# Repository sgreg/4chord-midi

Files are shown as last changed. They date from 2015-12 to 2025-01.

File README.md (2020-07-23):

# 4chord MIDI - The Four Chord USB MIDI Keyboard

What does it take to create a hit pop song?

Australia's former comedy group [The Axis of Awesome](https://en.wikipedia.org/wiki/The_Axis_of_Awesome) had the answer: [Four chords](https://www.youtube.com/watch?v=5pidokakU4I). Though not just any four chords, but the [I-V-vi-IV chord progression](https://en.wikipedia.org/wiki/I%E2%80%93V%E2%80%93vi%E2%80%93IV_progression) to be precise. This project implements a USB MIDI device for the purpose of playing this exact four-chord progression.

4chord MIDI is a regular USB MIDI controller, just like any other MIDI keyboard, except it has just four buttons, one for each chord in the I-V-vi-IV chord progression, playable in any key. But since simply playing chords is a bit limiting, it also features different playback modes such as triad arpeggios and chords mixed with arpeggios. Additionally, the tempo of each note progression is selectable from 30bpm to 240bpm. It's even shaped like a piano, to give the real feel of playing an actual musical instrument.

For additional information, check out [the 4chord MIDI project website](https://4chord.craplab.fi) and [its hackaday.io project page](https://hackaday.io/project/26078-4chord-midi).

4chord MIDI is fully open source and certified as such by the [Open Source Hardware Association (OSHWA)](https://www.oshwa.org/). The hardware is licensed under the [CERN Open Hardware License v.1.2](http://www.ohwr.org/projects/cernohl/wiki) and the software is released under the [GNU General Public License version 2](http://www.gnu.org/licenses/old-licenses/gpl-2.0.en.html).

<p align="center">
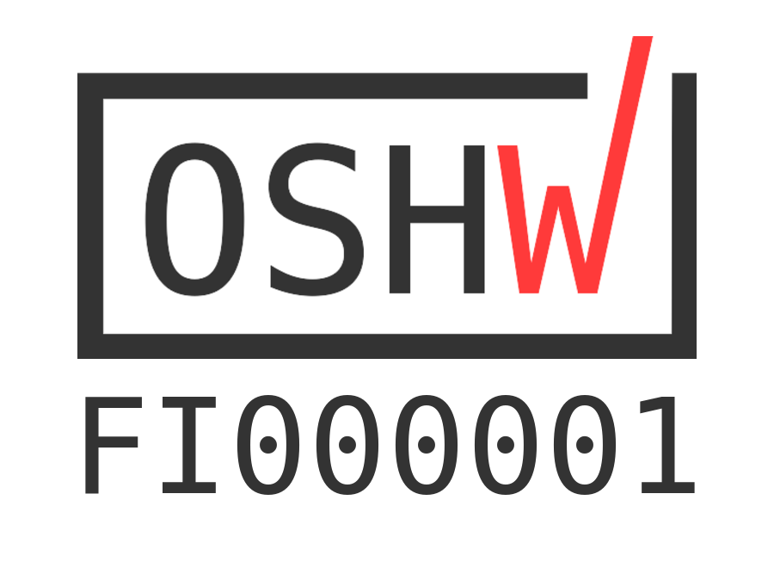
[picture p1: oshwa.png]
[OSHW] FI000001 Finland Number One!

</p>

## Table of Contents
  * [Quick Start](#quick-start)
  * [Project Structure](#project-structure)
  * [Build it](#build-it)
  * [Flash it](#flash-it)
  * [Use it](#use-it)
  * [User Interface](#user-interface)
  * [Troubleshooting](#troubleshooting)

## Quick Start

If you're not interested in the details, here's the quickest way to build and flash a 4chord MIDI device. Note that the Makefile is set up to expect USBasp as programmer. If you're using a different programmer, check the [flashing section](#flash-it) for more details.

### Dependencies
Make sure you have the dependencies to build the bootloader and firmware installed on your system.

For Ubuntu, Debian, and the likes, this should be:
```
$ sudo apt install gcc-avr avr-libc avr-binutils avrdude make
```
For Fedora etc. it should be:
```
$ sudo dnf install avr-gcc avr-libc avr-binutils avrdude make
```
For Arch it should be ~~FUCKING OBVIOUS AND YOU'RE NOT WORTHY TO USE THIS GLORIOUS DISTRO IF YOU HAVE TO ASK A LAME QUESTION LIKE THIS~~ the same package names as for Fedora:
```
$ sudo pacman -S avr-gcc avr-libc avr-binutils avrdude make
```

Unfortunately, I don't have the answer for any other distribution, MacOS, or Windows, but essentially, it's just the regular AVR toolchain components (and `make`), so checking a general setup guide for the AVR toolchain on that system should get you there. Presumably it follows the same package names as mentioned so far.

### Cloning, Building, Flashing

Clone the repository and change into it:
```
$ git clone https://github.com/sgreg/4chord-midi.git
$ cd 4chord-midi/
```

Build the bootloader and firmware:
```
$ make
```

Make sure the ATmega's fuses are set up properly:
```
$ make fuses
```

Flash it to the device:
```
$ make program
```

That's it, your 4chord MIDI device should be ready to go, and once plugged in, recognized as as such. Check the [usage section](#use-it) for a quick overview of how to connect it to *FluidSynth* to get your first chords played.

If you *are* interested in more details, well here they come.

## Project Structure

* [`bootloader/`](bootloader/) the bootloader for comfortable firmware update flashing
* [`doc/`](doc/) some relevant documentation such as USB specifications
* [`firmware/`](firmware/) the main 4chord MIDI firmware code
* [`graphics/`](graphics/) raw [XBM](https://en.wikipedia.org/wiki/X_BitMap) files used within the GUI and intro animation
* [`hardware/`](hardware/) schematic and PCB design files
* [`sys/`](sys/) Linux system scripts (udev rules and setup scripts)
* [`tools/`](tools/) additional tools to convert graphics and dump fuse settings
* [`Makefile`](Makefile) main entry point to built it all
* [`common.mk`](common.mk) shared data related to building
* everything else: this README and git stuff

## Build it

From firmware point of view, there are three main parts to build here:
1. the raw XBM graphics converted to easily dump to the Nokia LCD (shipped pre-built)
1. the bootloader for future firmware updates via USB (optional but recommended)
1. the actual firmware

### Graphics
As the graphics parts come pre-built ([`intro.c`](firmware/intro.c)/[`intro.h`](firmware/intro.h) for the intro animation, [`gfx.c`](firmware/gfx.c)/[`gfx.h`](firmware/gfx.h) for all GUI related graphic elements), there's nothing to do, unless you want to change the [`graphics/`](graphics/) content by either adding new XBM files, or modifying the existing ones. In that case, once the graphics are modified, run:
```
$ make graphics
```
from the project's root path, which will delete all previously generated files and re-create them.

### Bootloader

You can build and flash the bootloader on its own without the main 4chord MIDI firmware. If this is your first time with the code, you might want to skip this option and go straight to the [Bootloader with Firmware](#bootloader-with-firmware) section for now.

But let's say you want to play around with just the bootloader and flash the application firmware through USB later, or make modifications to the bootloader itself. In that case, the bootloader can be built from the project's root directory via
```
$ make bootloader
```

or from within the `bootloader/device/` directory via `make` on its own.

This will create the bootloader's ELF and HEX file in the `bootloader/device/` directory, ready to be flashed to the device. Instructions on flashing [follow below](#flash-it).

**Note that this will build only the bootloader but not the firmware, so the device won't act as USB MIDI controller afterwards!**

Also note that once [flashed](#flash-it), the bootloader needs to be manually activated by pressing the *Select* button when powering the device up, otherwise it will fall through to the application code - which in this case won't exist. As a result, the device is stuck in a boot loop until the *Select* key is pressed. In other words, if the device seems dead after flashing the bootloader, just press the *Select* button to start up the actual bootloader.

### Firmware

As with the bootloader mentioned above, the firmware can be built and flashed on its own without adding the bootloader to it. This makes sense if you make any changes to the firmware code without touching the bootloader, but keep in mind that [flashing](#flash-it) the firmware on its own will leave out the bootloader, so future firmware updates via USB won't be possible (but you can always just re-flash the device with both components, so there's no harm done).

To build the firmware on its own from the project root directory, simply call

```
$ make firmware
```

To build it straight from within the `firmware/` directory, simply run `make` in there.

This will again create the ELF and HEX file inside the `firmware/` directory, and in addition, a BIN file. The HEX file is used for [flashing](#flash-it), while the BIN file is used in the firmware upgrade via USB using the bootloader.

### Bootloader with Firmware

To get the full package of bootloader and firmware, simply call
```
$ make
```
from within the project's root directory.

This will build both components separately, and the resulting ELF, HEX, and in case of the firmware, BIN file will be afterwards located in `bootloader/device/` and `firmware/` respectively.

You should now have either one of them built and ready to be flashed to the device.

## Flash it

If you're building your own device, you will require an AVR programmer to flash the initial bootloader and/or firmware to it. If you got a ready-made device, it will come with an initial bootloader and firmware already flashed on it, in which case you can either still use an AVR programmer to update it, or use the bootloader's built-in update functionality.

### Flashing with an AVR Programmer

The build system is set up to expect USBasp as programmer, so if you're using a different programmer, flashing is of course going to fail. To set up the build system for your programmer, check the [`common.mk`](common.mk) file for the following line:

```
AVRDUDE_PROGRAMMER_FLAGS = -c usbasp
```
and adjust it to your needs. If the programmer requires an additional port parameter, add the `-P <port>` accordingly.

Note that the device uses a 6-pin ISP connector, although some programmers - including a regular USBasp programmer - comes with a 10-pin connector. The 10-pin version has in the end just 4 additional, unused pins, which seems unnecessary, so the choice was to go for the 6-pin version here. The connectors are otherwise compatible, it just needs either an adapter or manual wiring.

To make sure the programmer is set up properly, connect it to the 4chord MIDI device and run
```
$ make check-programmer
```
from within the project's root directory. If both the programmer and device was detected, you should `SUCCESS` displayed in the end. Note that if you didn't connect the 4chord MIDI device, you might still see `FAILURE` even though the programmer is set up correctly. `avrdude`'s error message should hopefully give some hints which part went wrong then.

If everything is happily set up, connect the programmer to the device and get ready to flash.

Depending on the parts you [built earlier](#build-it), you can either flash the bootloader and firmware on its own, or nicely combined for the full experience.

For the latter, run the following command from the project's root directory:
```
$ make program
```
To flash only the bootloader, which won't include the firmware itself and therefore won't turn the device into an actual MIDI controller, run the command from within the bootloader directory:
```
$ cd bootloader/device/
$ make program
```
To flash only the firmware without the bootloader, flash it from the firmware's directory accordingly:
```
$ cd firmware/
$ make program
```

In case you included the firmware in your flashing, you're ready to [use it](#use-it). If you only flashed the bootloader and want to add the firmware through it, keep reading.

### Flashing via Bootloader

Whether the device runs *only* the bootloader, or the whole package, as long as there's a bootloader, you can use it to flash the actual 4chord MIDI firmware on it.

Flashing the firmware via bootloader involves two parts:
1. the activated bootloader on the device
2. the host-side flashing tool

To activate the bootloader, press the *Select* button while you power up the device, i.e. keep the *Select* button pressed when you plug in the USB cable to either your computer or the device itself. Instead of the 4chord MIDI startup animation and its user interface, you'll be greeted by the bootflash screen, telling you to feed it firmware.

The [host-side flashing tool](bootloader/host/) is a Python script using [PyUSB](https://github.com/pyusb/pyusb) to communicate with the bootloader - so make sure you have both Python 3 and the PyUSB module installed, whether through `pip` or your Linux distro's package manager.

With the device set up to receive new firmware, change into the host-side flashing tool's directory and run the script, giving the path of the new firmware's BIN file. If you built the firmware from its regular location, it will look like this:
```
$ cd bootloader/host/
$ ./bootflash.py ../../firmware/4chordmidi.bin
```

As you run the script, you will see some information and progress status displayed on the command line, and the device will show a progress bar on its screen. Once everything is done, you're ready to boot into the new firmware.

You can either just unplug the cable and plug it back in (making sure not to press the *Select* button this time), or press the *I* and *IV* playback button (i.e. the left-most and right-most white buttons).

## Use it

This section exclusive covers using the device under Linux, but since 4chord MIDI implements standard USB and MIDI specifications, other operating systems should treat it just like any other MIDI device. The general instructions of using MIDI devices on other operating systems should therefore apply also to 4chord MIDI.

### Plug it in

Connect 4chord MIDI to your computer and check if it got recognized. `dmesg` or the system log should show something like this:
```
[3038097.883853] usb 1-1.1.1: new low-speed USB device number 112 using ehci-pci
[3038099.140623] usb 1-1.1.1: New USB device found, idVendor=1209, idProduct=deaf
[3038099.140626] usb 1-1.1.1: New USB device strings: Mfr=1, Product=2, SerialNumber=0
[3038099.140627] usb 1-1.1.1: Product: 4chord MIDI
[3038099.140628] usb 1-1.1.1: Manufacturer: CrapLab
```

And thanks to [pid.codes](http://pid.codes/), `lsusb` should show something like this:
```
Bus 001 Device 112: ID 1209:deaf Generic CrapLab 4chord MIDI
```
Of course, the bus and device number will most certainly differ, but as long as the VID/PID pair (`1209:deaf`) is the same, it's all good.

### Simple playback with FluidSynth

As 4chord MIDI is just the controller in the MIDI chain, you will need a synthesizer to turn the playback into actual music. A cross-platform choice for this is for example the [FluidSynth software synthesizer](https://en.wikipedia.org/wiki/FluidSynth) in combination with its related sound font files.

FluidSynth can use different audio driver, including ALSA, PulseAudio, and [jack](https://en.wikipedia.org/wiki/JACK_Audio_Connection_Kit). To make life easy, let's use ALSA for this example.

#### Dependencies
Here's how to install ALSA utilities, FluidSynth with the sound fonts, and the resulting path of the sound font file we'll need afterwards.

Ubuntu / Debian / etc:
```
$ sudo apt install fluidsyinth fluid-soundfont-gm alsa-utils
/usr/share/sounds/sf2/FluidR3_GM.sf2
```
Note that the soundfont might also be named `fluidsynth-soundfont-gm` in older versions

Fedora etc:
```
$ sudo dnf install fluidsynth fluid-soundfont-gm alsa-utils
/usr/share/soundfonts/FluidR3_GM.sf2
```
Arch:
```
$ sudo pacman -S fluidsynth soundfont-fluid alsa-utils
/usr/share/soundfonts/FluidR3_GM.sf2
```

Again, for other distributions and operating systems, check the internet.

#### Running FluidSynth

Open up a terminal and start FluidSynth:

```
$ fluidsynth -a alsa -m alsa_seq /usr/share/soundfonts/FluidR3_GM.sf2
```

Make sure to use the correct sound font path according to your distro / operating system.

Once FluidSynth is started, and a 4chord MIDI device is connected to your computer, we need to connect the two using `aconnect` from the ALSA utils. Open up another terminal and check the input and output port IDs of the two parties involved.

```
$ aconnect -i
client 20: '4chord MIDI' [type=kernel]
    0 '4chord MIDI MIDI 1'

$ aconnect -o
client 129: 'FLUID Synth (32590)' [type=user]
    0 'Synth input port (32590:0)'
```

Your output probably shows more devices in each command, but those are the ones to look for. It tells us that 4chord MIDI is input port `20:0` and FluidSynth as MIDI output is port `129:0`. All that's left to do is connect the two:

```
$ aconnect 20:0 129:0
```

That's it. If you press any of the white playback buttons, you should hear a piano sound of the chords. Congratulations!

#### Changing instruments

If you want a change from the default Yamaha Grand Piano, go back to the terminal that runs FluidSynth and check the list of available instruments within its own command line. Since there's only one sound font file, its ID is simply `1`.
```
> inst 1
000-000 Yamaha Grand Piano
000-001 Bright Yamaha Grand
000-002 Electric Piano
...
000-025 Steel String Guitar
...
>
```

Changing the playback instrument for example to the Steel String Guitar (instrument id 25) for the default MIDI channel 0 is done via the `prog <chan> <instrument>` command:
```
> prog 0 25
```

You should now hear a guitar sound from the 4chord MIDI device.

### Automatic FluidSynth Setup

If you want to start FluidSynth automatically when you connect a 4chord MIDI device to you computer, you can do so on Linux with a udev rule. Check the [`sys/udev/`](sys/udev/) directory for further information on that.

## User Interface

If you got this far and everything worked as described, congratulations once again - and to both of us I guess, seeing that what I wrote actually worked out. If it didn't, well, there's a [troubleshooting section](#troubleshooting) still to come.

Now that the device is ready to be fully used, it's time give a quick introduction to its user interface.

### Display

The display consists of 4 components:
1. the menu bar on top, showing key, mode, tempo, and metre, underlining the one currently active
1. the playback setup information in form of key (C, C#, ..., Bb), tempo (30...240), metre (4/4, 3/4. 6/8), and playback mode (chord, arpeggios - shown in a simple form of musical notation)
1. the available chords for the currently selected key, highlighting the one that is currently played
1. a metronome if the playback mode is not just the simple chord playback

The menu buttons will control the content on the display.

### Menu Buttons
The three black buttons - `<`, `Select`, and `>` - serve as menu buttons and are used to control the key, mode, tempo, and metre:
* `Select` toggles between which part to control, i.e. key, mode, tempo, or metre
* `<` and `>` choose each part's value in an down/up and previous/next manner respectively

For example, if the *key* is the active component, and the active key is "C", `<` will change it to "Bb", and `>` will change it to "C#". Pressing `Select` twice will set the active component to `tempo`, and `<` will not decrease it, while `>` will increase it.

Both `<` and `>` have a long-press feature, meaning if keeping the button pressed, multiple press events are recognized, eventually speeding up.

For the time being, a long press on the `Select` button will save the current setup (key, mode, tempo, metre) as the device's default settings, so next time the device is powered on, it will recover those as its initial state.

### Playback buttons

The four playback buttons - `I`, `V`, `vi`, `IV` - are used to play each one of the four chords. That's basically it.

And yes, this section could most certainly use some visual aid.

## Troubleshooting

Obviously, everything I write and explain *works for me*&trade;, so it's difficult to anticipate difficulties others might have. Therefore the list of known problems is pretty limited at this point, but feel free to open an issue or contact me you come across some problems yourself.

#### Nothing happens when plugging in the device, and the display stays black
The flash might be either empty, or only the bootloader was flashed. Press the *Select* button and see if a bootflash screen comes up on the display. If yes, the application side wasn't flashed. If not, try re-flashing everything. See the [flashing section](#flash-it) either way.

#### Flashing firmware via bootloader fails with `usb.core.USBError: [Errno 13] Access denied (insufficient permissions)`
The device permissions are not set up for your user. You can either use `sudo`, or check the [bootloader/ directory](bootloader/) README about setting up a udev rule.

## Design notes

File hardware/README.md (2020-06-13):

# 4chord MIDI schematic and PCB layout files

**Note:** All content was designed using KiCad 4. This should be updated to KiCad 5 eventually. Schematics are additionally provided in PDF and PCB layouts in Gerber format.

## Subdirectory content:

- Atmega328-TQFP32:
    - SMD version
    - 32pin TQFP ATmega328
    - Nokia 5110 clip-in LCD

## Notes on the Nokia 5110 LCD
There are several options to source the LCD with its clip-in frame, the most common one being the breakout board version of it. In some cases you might find the standalone LCD without breakout board.

KiCad didn't have footprints for it, so I created one that is available in my [kicad-libs repo](https://github.com/sgreg/kicad-libs), with more information available [on its dedicated hackady.io project page](https://hackaday.io/project/25666-yet-another-nokia-5110-lcd-breakout-board).

## Notes on PCB artwork
As with the LCD connector footprints, the logos used on the PCB can be found in my [kicad-libs repo](https://github.com/sgreg/kicad-libs).

## License
The 4chord MIDI documentation is released as Open Hardware under the CERN OHL v.1.2.

You may redistribute and modify this documentation under the terms of the [CERN OHL v.1.2](http://ohwr.org/cernohl).
This documentation is distributed WITHOUT ANY EXPRESS OR IMPLIED WARRANTY, INCLUDING OF MERCHANTABILITY, SATISFACTORY QUALITY AND FITNESS FOR A PARTICULAR PURPOSE. Please see the CERN OHL v.1.2 for applicable conditions

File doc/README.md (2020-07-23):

## Documentation

A selection of documentation and specifications relevent to 4chord MIDI.

The original locations are linked within the firmware code, e.g. [`usb.h`](../firmware/usb.h). However, those locations have changed in the past, and old links resulted in 404 or redirects. To make everyone's life easier in case it happens again at some point in the future, I just added their copies here.

### Content

* [`audio10.pdf`](audio10.pdf) _USB Device Class Specification for Audio Devices_  
originally found at https://usb.org/sites/default/files/audio10.pdf
* [`midi10.pdf`](midi10.pdf) _USB Device Class Specification for MIDI Devices_  
originally found at https://usb.org/sites/default/files/midi10.pdf
* [`Summary_of_MIDI_Messages.pdf`](Summary_of_MIDI_Messages.pdf) _Summary of MIDI Messages_ table as found at https://www.midi.org/specifications/item/table-1-summary-of-midi-message (basically printed that page to PDF)

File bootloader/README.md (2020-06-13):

# 4chord MIDI Bootloader

The bootloader allows to update the 4chord MIDI firmware through USB. It uses a rather simple, home-brew protocol to set up the firmware transfer, transfer and flash the firmware itself, as well as writing EEPROM data. It consists of a host-side and a device-side part, with the host side initiating the transfer, and the device-side flashing chunks of the new firmware file as it receives it.

## Protocol

The protocol used to communicate between the host-side Python script and the device-side firmware uses USB control transfers and looks like this:

| Command | Type | Hex |  Description |
| --- | ---- |  --- | ---- |
| HELLO | Recv | `0x01` | Initiates communication and retrieves the bootloader version string of size 'buffer'|
| FWUPDATE_INIT | Send | `0x10` | Initiates firmware transfer, giving the number of expected 128 byte chunks|
| FWUPDATE_MEMPAGE  | Send | `0x11` | Transfer a single firmware chunk |
| FWUPDATE_VERIFY | Recv | `0x12` | Read back the last transferred firmware chunk for verification |
| FWUPDATE_FINALIZE | Send | `0x13` | Finalize firmware transfer |
| EEPROM_READ | Recv | `0x20` | Read EEPROM value from a given address |
| EEPROMT_WRITE | Send | `0x30` | Write EEPROM value to a given address |
| BYE | Send | `0xf0` | Terminate the communication |
| RESET | Send | `0xfa` | Reset the device |

With the Python script being the initiating side, the Recv/Send type refers to its point of view.

### Device Side

On the device side, the bootloader firmware is located in the ATmega's dedicated bootloader memory section, and the communication is implemented via V-USB.

#### State machine

There's a simple state machine on the device side making sure that everything has its order.

| State | Description
|  --- | --- |
| IDLE | No communication initiated, requires `HELLO` command |
| HELLO | Communication initiated, ready to either start firmware update via `FWUPDATE_INIT` command or EEPROM operations |
| FWUPDATE | Firmware update ongoing, only `FWUPDATE_*` related commands are handled |
| RESET | Device reset initiated

#### Debug build

In case you want to modify the device-side bootloader firmware and have to debug something, it can be built with a `DEBUG` flag that adds extra debug output via UART. However, due to size limitations, enabling UART debug will disable graphical output on the LCD. So it's either LCD or UART, and without the `DEBUG` flag, no UART functions are available. Also, flashing with debug output enabled is really slow.

If you switch between `DEBUG` and normal built, it's best to `make clean` between the builds.

### Host Side

To run the host-side bootflash script, Python 3, PyUSB, and a udev rule to allow access to the device is needed. Using `sudo` or being root will also do for the latter, but nothing wrong with a udev rule to make life easier.

#### udev rule

There are two options to set up the permissions: set the device ownership to the current user, or set the device's read and write permission for everyone. The more flexible one is the latter, and would like this:

```
SUBSYSTEM=="usb", ATTRS{idVendor}=="1209", ATTRS{idProduct}=="deaf", MODE="0666"
```

You can either manually copy this to a udev file in `/etc/udev/rules.d/`, or use the installation script in the repository's [`sys/udev/` directory](../sys/udev/) to do it automatically.

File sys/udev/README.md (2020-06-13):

## 4chord MIDI udev rule example

Just some proof of concept to have a script run whenever a 4chord MIDI device is plugged in and unplugged. In this case, it will automatically setup the MIDI connection to fluidsynth when the device is plugged in. If fluidsynth isn't running, it will start it. When the device is unplugged, everything is nicely cleaned up again.

In addition, another rule will set up the permission for the device so any user can flash it via the bootloader.

There are a few files to get this done:

* `4chordMIDI-bootflash.rules` the udev rule file to set up the permission
* `4chordMIDI-fluidsynth.sh` the actual script taking care of the whole fluidsynth and MIDI connection setup handling
* `4chordMIDI-fluidsynth.rules` the udev rule template that will actually handle the script execution
* `install.sh` installation script to set it all up

The udev rule will executed by root while the whole fluidsynth and MIDI setup needs to be run by a regular user, so the script needs to be executed using `su - <user>` to make it work properly. The user name needs to be hard coded to the udev rule file, so to avoid doing this manually, I added the `install.sh` script. It also lets you choose the udev rule file prefix.

### Known Issues

The udev rule doesn't seem to work too well with (at least) Arch Linux. While the `4chordMIDI-fluidsynth.sh` script gets executed, and fluidsynth is trying to start, it doesn't succeed due to some underlything ALSA issues. Possibly just some configuration issue but haven't gotten around to finding a solution yet.
 - **Workaround 1**: have the udev rule still in place, but start fluidsynth manually *before* plugging in the 4chord MIDI device
 - **Workaround 2**: ditch the whole udev part and run `4chordMIDI-fluidsynth.sh` manually *after* plugging in the device

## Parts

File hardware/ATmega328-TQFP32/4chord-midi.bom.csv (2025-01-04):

Reference | Value | Datasheet | Footprint | Qty | DNP
C1,C2 | 10u |  | Capacitors_Tantalum_SMD:CP_Tantalum_Case-A_EIA-3216-18_Hand | 2
C3,C4,C5,C8,C9,C10,C11,C12,C13,C14,C15,C16 | 100n |  | Capacitors_SMD:C_0805_HandSoldering | 12
C6,C7 | 27p |  | Capacitors_SMD:C_0805_HandSoldering | 2
D1,D2,D3,D4 | LED |  | LEDs:LED_0805 | 4
IC1 | ATMEGA328P-A |  | Housings_QFP:TQFP-32_7x7mm_Pitch0.8mm | 1
P1 | USB_B |  | Connect:USB_Mini-B | 1
P2 | Programmer |  | Connect:IDC_Header_Straight_6pins | 1
P3 | UART |  | Pin_Headers:Pin_Header_Straight_1x04_Pitch2.54mm | 1
P4 | UART Power |  | Pin_Headers:Pin_Header_Straight_1x04_Pitch2.54mm | 1
Q1 | 2N7002 |  | TO_SOT_Packages_SMD:SOT-23 | 1
R1,R2 | 68R |  | Resistors_SMD:R_0805_HandSoldering | 2
R3 | 1k5 |  | Resistors_SMD:R_0805_HandSoldering | 1
R4,R17 | 1M |  | Resistors_SMD:R_0805_HandSoldering | 2
R5,R6,R7,R8,R9,R10,R11,R18 | 10k |  | Resistors_SMD:R_0805_HandSoldering | 8
R12,R13,R14,R15,R16 | 100 |  | Resistors_SMD:R_0805_HandSoldering | 5
SW1 | < |  | Buttons_Switches_SMD:SW_SPST_EVPBF | 1
SW2 | Select |  | Buttons_Switches_SMD:SW_SPST_EVPBF | 1
SW3 | > |  | Buttons_Switches_SMD:SW_SPST_EVPBF | 1
SW4 | I |  | Buttons_Switches_SMD:SW_SPST_EVPBF | 1
SW5 | V |  | Buttons_Switches_SMD:SW_SPST_EVPBF | 1
SW6 | vi |  | Buttons_Switches_SMD:SW_SPST_EVPBF | 1
SW7 | IV |  | Buttons_Switches_SMD:SW_SPST_EVPBF | 1
U1 | LD1117S33CTR |  | TO_SOT_Packages_SMD:SOT-223 | 1
U2 | Nokia_5110_LCD |  | Nokia_5110-3310_LCD:Nokia_5110-3310_LCD | 1
X1 | 12MHz |  | Crystals:Crystal_SMD_HC49-SD | 1

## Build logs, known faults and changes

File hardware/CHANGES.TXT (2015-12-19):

********************************************************************************
*                                 CHANGES.TXT                                  *
********************************************************************************
Modifications made by Licensee.

********************************************************************************

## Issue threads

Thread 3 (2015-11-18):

Add USB MIDI handling

sgreg, 2015-11-18:
Implement basic USB MIDI support via V-USB.
* Setup as MIDI device
* Single note MIDI command send on chord button key press

sgreg, 2015-11-22:
Completed with pull request #6 merge

Closed 2015-11-22.

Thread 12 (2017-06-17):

Create Revision B schematic

sgreg, 2017-06-17:
Update schematic for Revision B

* Change crystal
* Change LCD + back light

sgreg, 2017-07-02:
Changed crystal, LCD and back light. Adjusted pins for better PCB routing

Closed 2017-07-02.

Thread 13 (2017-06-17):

Create Revision B PCB

sgreg, 2017-06-17:
Create a more interesting PCB and add issue #12 changes.

sgreg, 2017-07-02:
New PCB designed and routed, left some debug options around for now (zero ohm links to power supplies, UART interface)

Closed 2017-07-02.

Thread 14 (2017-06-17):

Update firmware to Revision B hardware changes

sgreg, 2017-06-17:
Adjust clock speed to lower speed crystal and any other changes (e.g. pin assignments)

sgreg, 2017-07-02:
* V-USB pins need adjustments, too
* new LCD needs different bias system configuration (`0x14` vs `0x12`)
* LCD backlight *handling* not part of this issue, only its pin assignment

sgreg, 2017-07-23:
Set firmware version to 1.1 after all the adjustments and create release "Firmware version 1.1, Hardware revision B" as clear base between initial Rev.A version and any changes coming for next firmware versions.

sgreg, 2017-07-23:
All adjustments done, at least in theory, there's no way to fully verify it without the hardware. Waiting for PCBs to arrive before closing the issue.

Closed 2017-08-01.

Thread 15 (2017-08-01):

Create Revision B.1 PCB

sgreg, 2017-08-01:
Revision B PCB needs some minor modifications:

- LCD back light transistor uses wrong component that messes up pin assignment
- move from bipolar transistor to MOSFET along the way
- zero Ohm links won't be necessary anymore
- button foot print is not an ideal fit for buttons in use, either one needs some changing
- UART connector's VCC pin needs a voltage selector for 0V, 3.3V, 5V to keep flexibility with serial connectors (used as debug interface for developers)
- additional rubber foot required on the top side, otherwise board topples when pressing "<" button
- some silk screen adjustments (button text needs to be lower, polarized capacitors lack polarity markings)

sgreg, 2017-08-19:
Everything done, Revision B hardware is now ready \o/

szwesleyzhao, 2017-08-19:
Cool, do you need turnkey pcb assembly service in china ? We could one stop stop service from prototype to mass production. Here is email; szhwpcba@gmail.com

sgreg, 2017-08-19:
Thanks, but I got everything I need covered for now.

Closed 2017-08-19.

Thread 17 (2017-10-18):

Add bootloader

sgreg, 2017-10-18:
Implement USB bootloader to firmware for updating itself:
* execute if "Select" menu key is pressed during power up
* show on LCD that bootloader is active
* wait for host side transfer initiation and firmware meta data (version, size, ...)
* receive firmware one memory page at a time and write it to flash
* read back freshly written flash page and send it back to host
* continue until host is happy and firmware is fully updated

Implement host side tool:
* simple Python CLI script
* search for right VID:PID and connect to it
* read firmware image and send one page at a time
* read back memory page from device and verify content - either re-send or move on

Update Makefile:
* build both bootloader and application firmware
* convert application firmware .hex file to binary blob data

sgreg, 2017-10-25:
Done and merged in #26

Closed 2017-10-25.

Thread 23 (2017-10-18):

Improve LCD handling

sgreg, 2017-10-18:
Currently the LCD content is buffered in the microcontroller RAM which takes up a large chunk of it. See if it's feasible to remove the buffering and update the LCD on the fly (as in [xbm2nokia](https://github.com/sgreg/xbm2nokia)).

Add funky startup animation along the way.

sgreg, 2017-10-20:
Also time to retire tools/create_graphics.* at that point and integrate [xbm2nokia](https://github.com/sgreg/xbm2nokia).

sgreg, 2017-10-28:
Done in #27 - no more useless buffering in RAM.

Didn't do the tool change though, still using the old tools/create_graphics.sh based script instead of xbm2nokia. Some other day..

Closed 2017-10-28.

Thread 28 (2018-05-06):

Integrate xbm2nokia

sgreg, 2018-05-06:
There's currently a mix of using the old graphics creation script and fixed graphics created by [xbm2nokia](https://github.com/sgreg/xbm2nokia). The old script should be fully replaced with xbm2nokia and integrated into the build system accordingly.

Closed 2018-12-23.

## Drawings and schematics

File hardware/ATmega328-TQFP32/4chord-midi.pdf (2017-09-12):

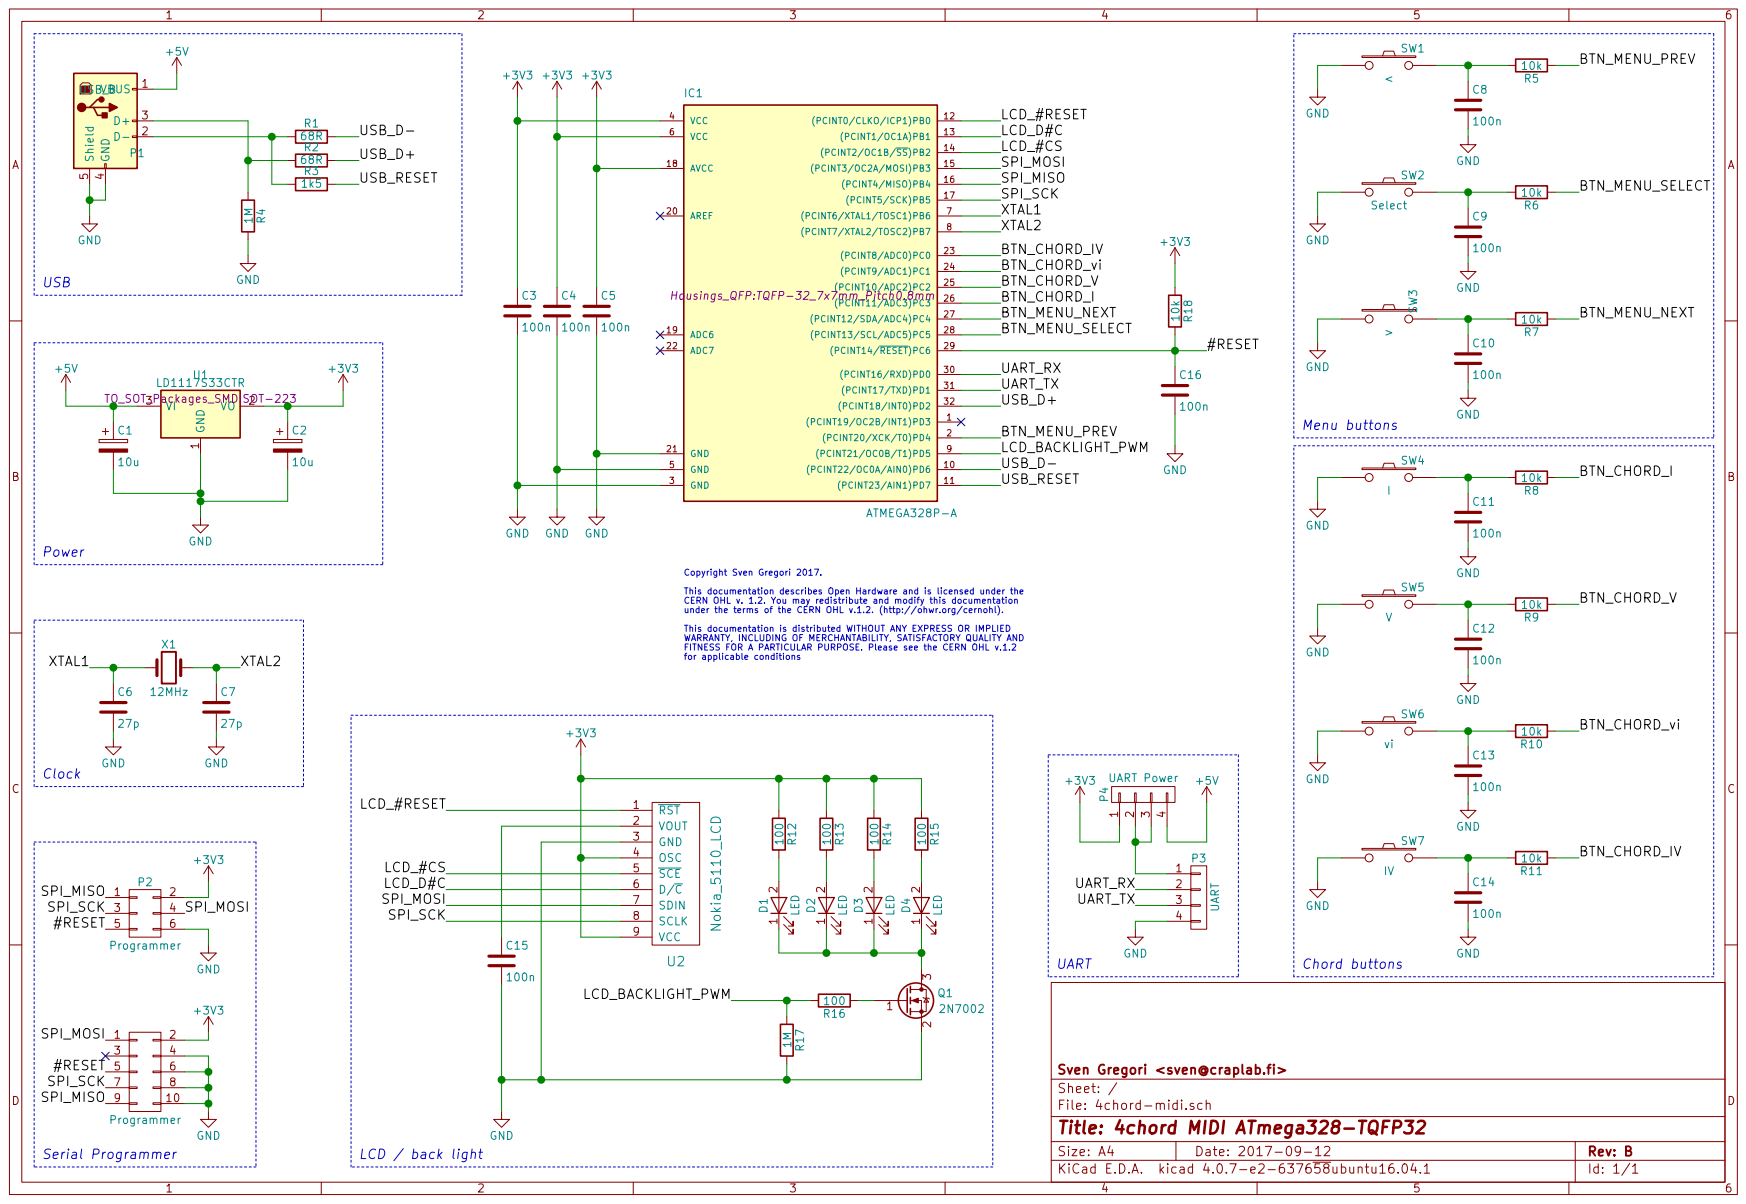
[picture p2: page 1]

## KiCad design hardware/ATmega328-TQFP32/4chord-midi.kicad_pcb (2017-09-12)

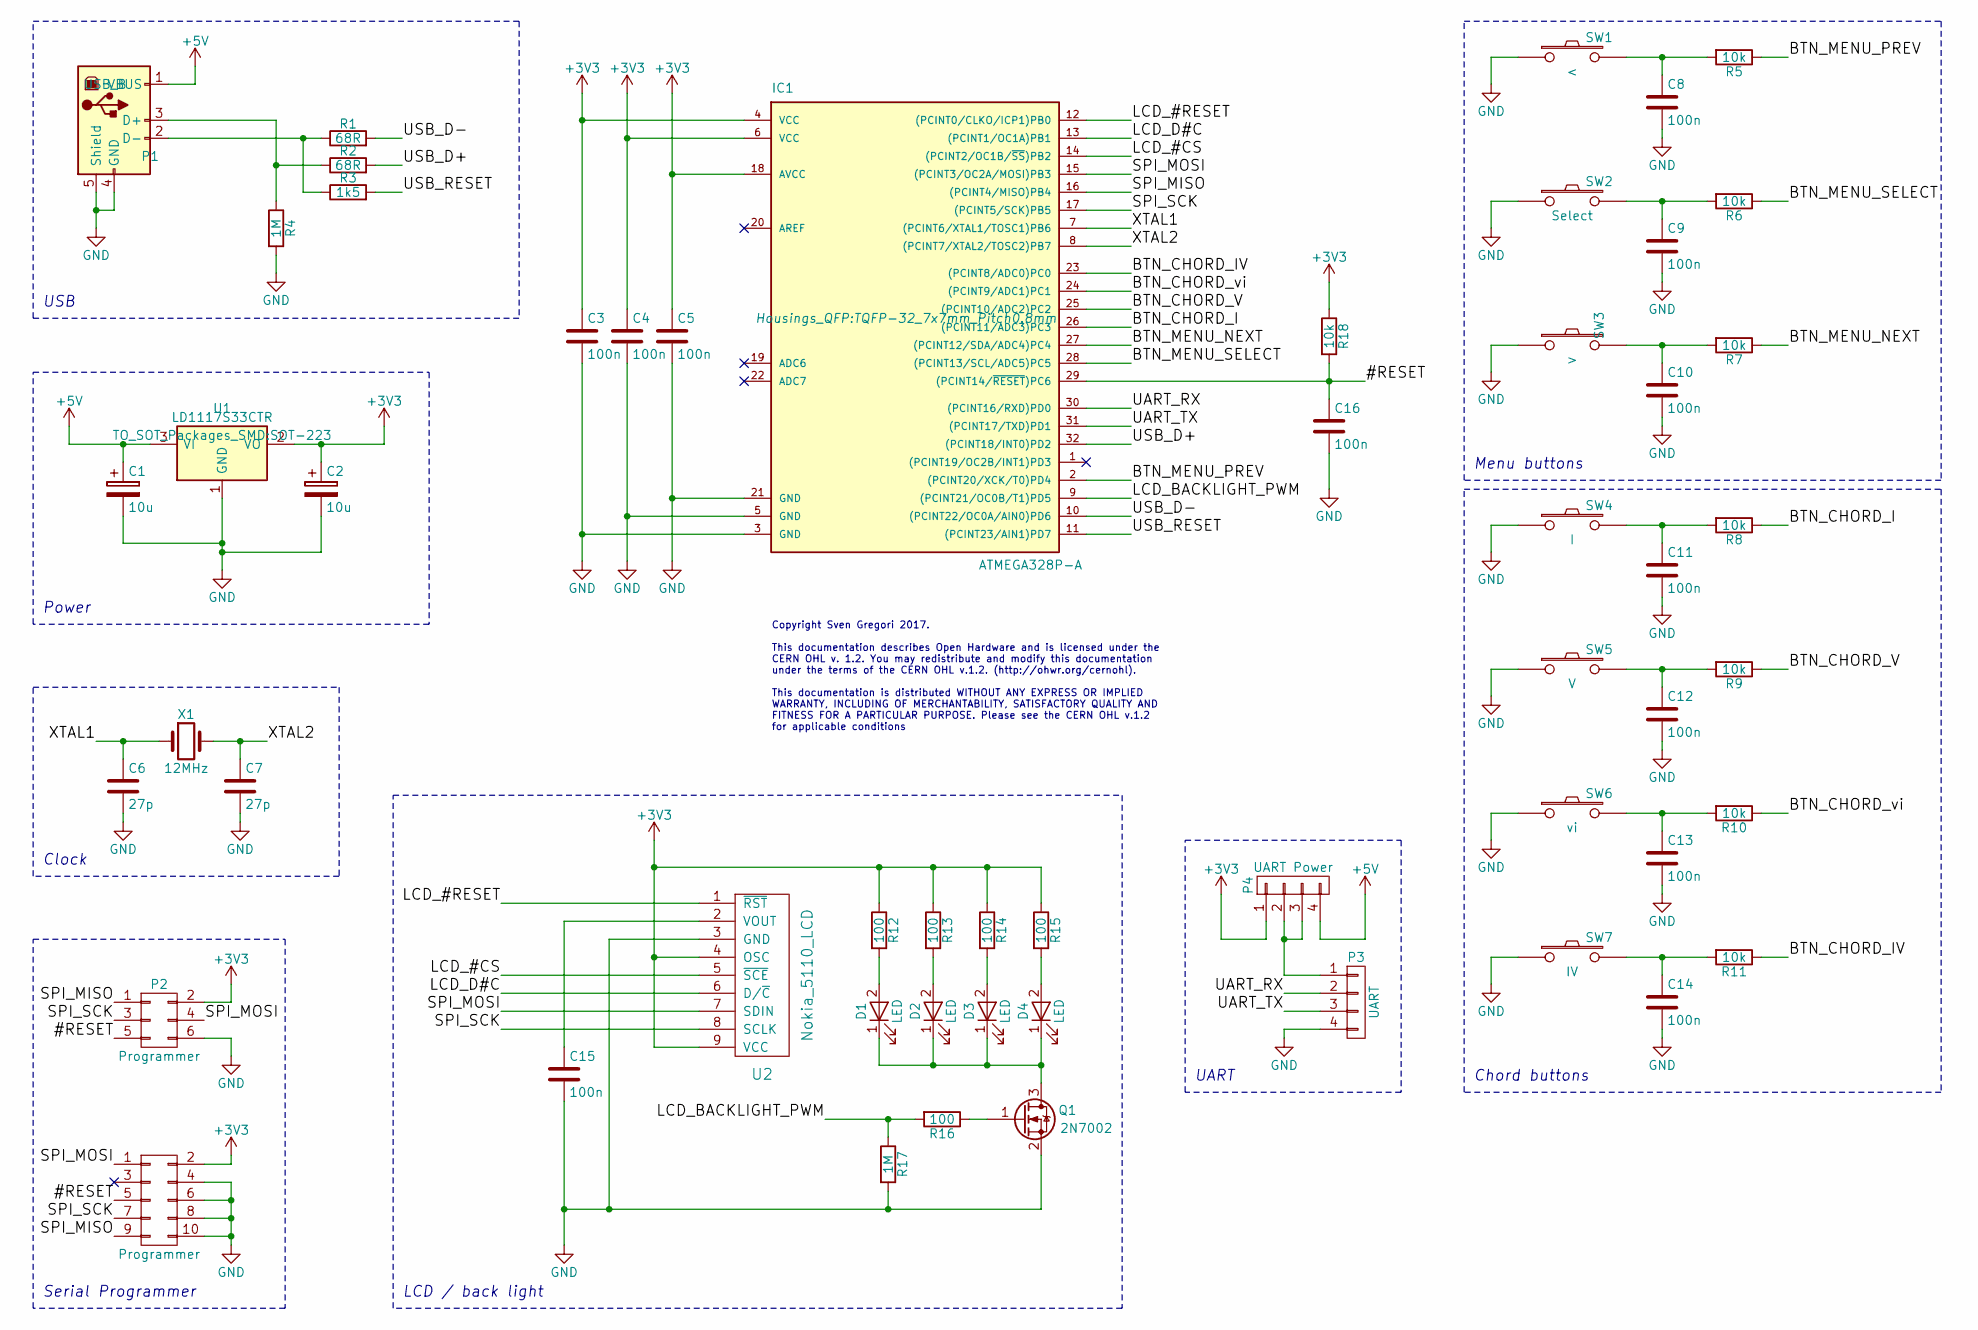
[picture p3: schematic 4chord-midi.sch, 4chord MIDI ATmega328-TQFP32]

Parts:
C1, C2: 10u; CP_Tantalum_Case-A_EIA-3216-18_Hand
C3, C4, C5, C8, C9, C10, C11, C12, C13, C14, C15, C16: 100n; C_0805_HandSoldering
C6, C7: 27p; C_0805_HandSoldering
D1, D2, D3, D4: LED; LED_0805
IC1: ATMEGA328P-A; TQFP-32_7x7mm_Pitch0.8mm
P1: USB_B; USB_Mini-B
P2: Programmer; IDC_Header_Straight_6pins
P3: UART; Pin_Header_Straight_1x04_Pitch2.54mm
P4: UART Power; Pin_Header_Straight_1x04_Pitch2.54mm
Q1: 2N7002; SOT-23
R1, R2: 68R; R_0805_HandSoldering
R3: 1k5; R_0805_HandSoldering
R4, R17: 1M; R_0805_HandSoldering
R5, R6, R7, R8, R9, R10, R11, R18: 10k; R_0805_HandSoldering
R12, R13, R14, R15, R16: 100; R_0805_HandSoldering
SW1: <; SW_SPST_EVPBF
SW2: Select; SW_SPST_EVPBF
SW3: >; SW_SPST_EVPBF
SW4: I; SW_SPST_EVPBF
SW5: V; SW_SPST_EVPBF
SW6: vi; SW_SPST_EVPBF
SW7: IV; SW_SPST_EVPBF
U1: LD1117S33CTR; SOT-223
U2: Nokia_5110_LCD; Nokia_5110-3310_LCD
X1: 12MHz; Crystal_SMD_HC49-SD

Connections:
+5V: C1.1, P1.1 (VBUS), P4.4, U1.3 (VI)
/BTN_CHORD_I: IC1.26 ((PCINT11/ADC3)PC3), R8.1
/BTN_CHORD_IV: IC1.23 ((PCINT8/ADC0)PC0), R11.1
/BTN_CHORD_V: IC1.25 ((PCINT10/ADC2)PC2), R9.1
/BTN_CHORD_vi: IC1.24 ((PCINT9/ADC1)PC1), R10.1
/BTN_MENU_NEXT: IC1.27 ((PCINT12/SDA/ADC4)PC4), R7.1
/BTN_MENU_PREV: IC1.2 ((PCINT20/XCK/T0)PD4), R5.1
/BTN_MENU_SELECT: IC1.28 ((PCINT13/SCL/ADC5)PC5), R6.1
/LCD_#CS: IC1.14 ((PCINT2/OC1B/~SS~)PB2), U2.5 (~SCE)
/LCD_#RESET: IC1.12 ((PCINT0/CLKO/ICP1)PB0), U2.1 (~RST)
/LCD_BACKLIGHT_PWM: IC1.9 ((PCINT21/OC0B/T1)PD5), R16.2, R17.1
/LCD_D#C: IC1.13 ((PCINT1/OC1A)PB1), U2.6 (D/~C)
/UART_RX: IC1.30 ((PCINT16/RXD)PD0), P3.2
/UART_TX: IC1.31 ((PCINT17/TXD)PD1), P3.3
/USB_D+: IC1.32 ((PCINT18/INT0)PD2), R2.2
/USB_D-: IC1.10 ((PCINT22/OC0A/AIN0)PD6), R1.2
/USB_RESET: IC1.11 ((PCINT23/AIN1)PD7), R3.2
/XTAL1: C6.1, IC1.7 ((PCINT6/XTAL1/TOSC1)PB6), X1.1
/XTAL2: C7.1, IC1.8 ((PCINT7/XTAL2/TOSC2)PB7), X1.2
unnamed: C8.1, R5.2, SW1.2
unnamed: C9.1, R6.2, SW2.2
unnamed: C10.1, R7.2, SW3.2
unnamed: C11.1, R8.2, SW4.2
unnamed: C12.1, R9.2, SW5.2
unnamed: C13.1, R10.2, SW6.2
unnamed: C14.1, R11.2, SW7.2
unnamed: C15.1, U2.2 (VOUT)
unnamed: D1.1 (K), D2.1 (K), D3.1 (K), D4.1 (K), Q1.3 (D)
unnamed: D1.2 (A), R12.2
unnamed: D2.2 (A), R13.2
unnamed: D3.2 (A), R14.2
unnamed: D4.2 (A), R15.2
unnamed: P1.2 (D-), R1.1, R3.1
unnamed: P1.3 (D+), R2.1, R4.1
unnamed: P3.1, P4.2, P4.3
unnamed: Q1.1 (G), R16.1

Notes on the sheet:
Copyright Sven Gregori 2017. This documentation describes Open Hardware and is licensed under the CERN OHL v. 1.2. You may redistribute and modify this documentation under the terms of the CERN OHL v.1.2. (http://ohwr.org/cernohl). This documentation is distributed WITHOUT ANY EXPRESS OR IMPLIED WA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
Clock
Serial Programmer
LCD / back light
Power
USB
UART
Menu buttons
Chord buttons

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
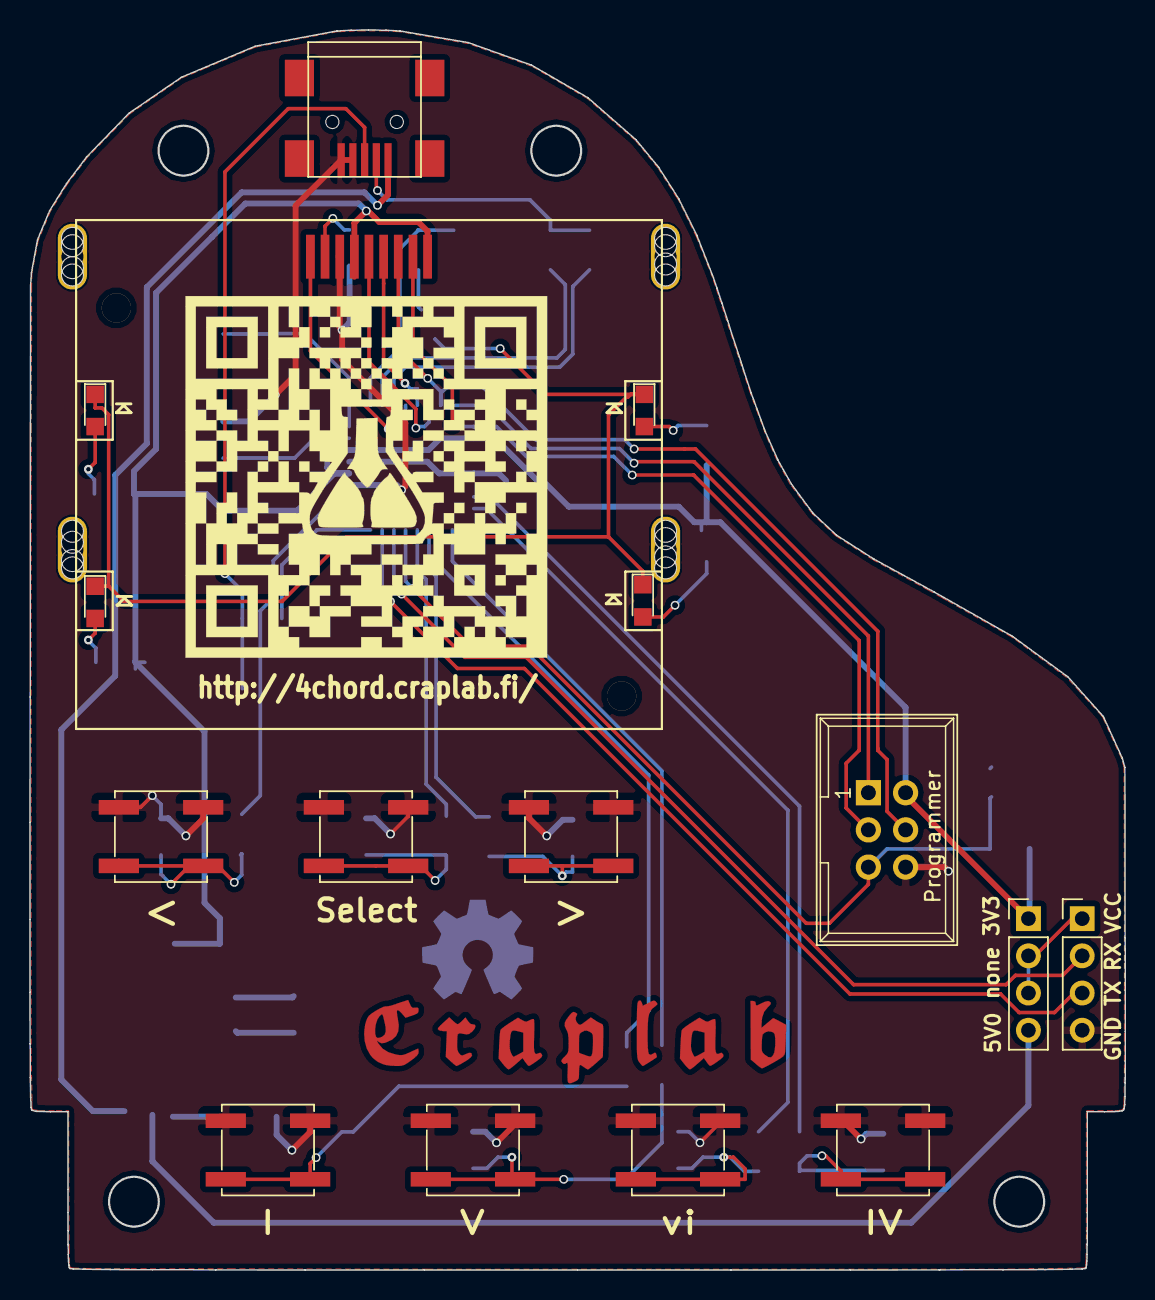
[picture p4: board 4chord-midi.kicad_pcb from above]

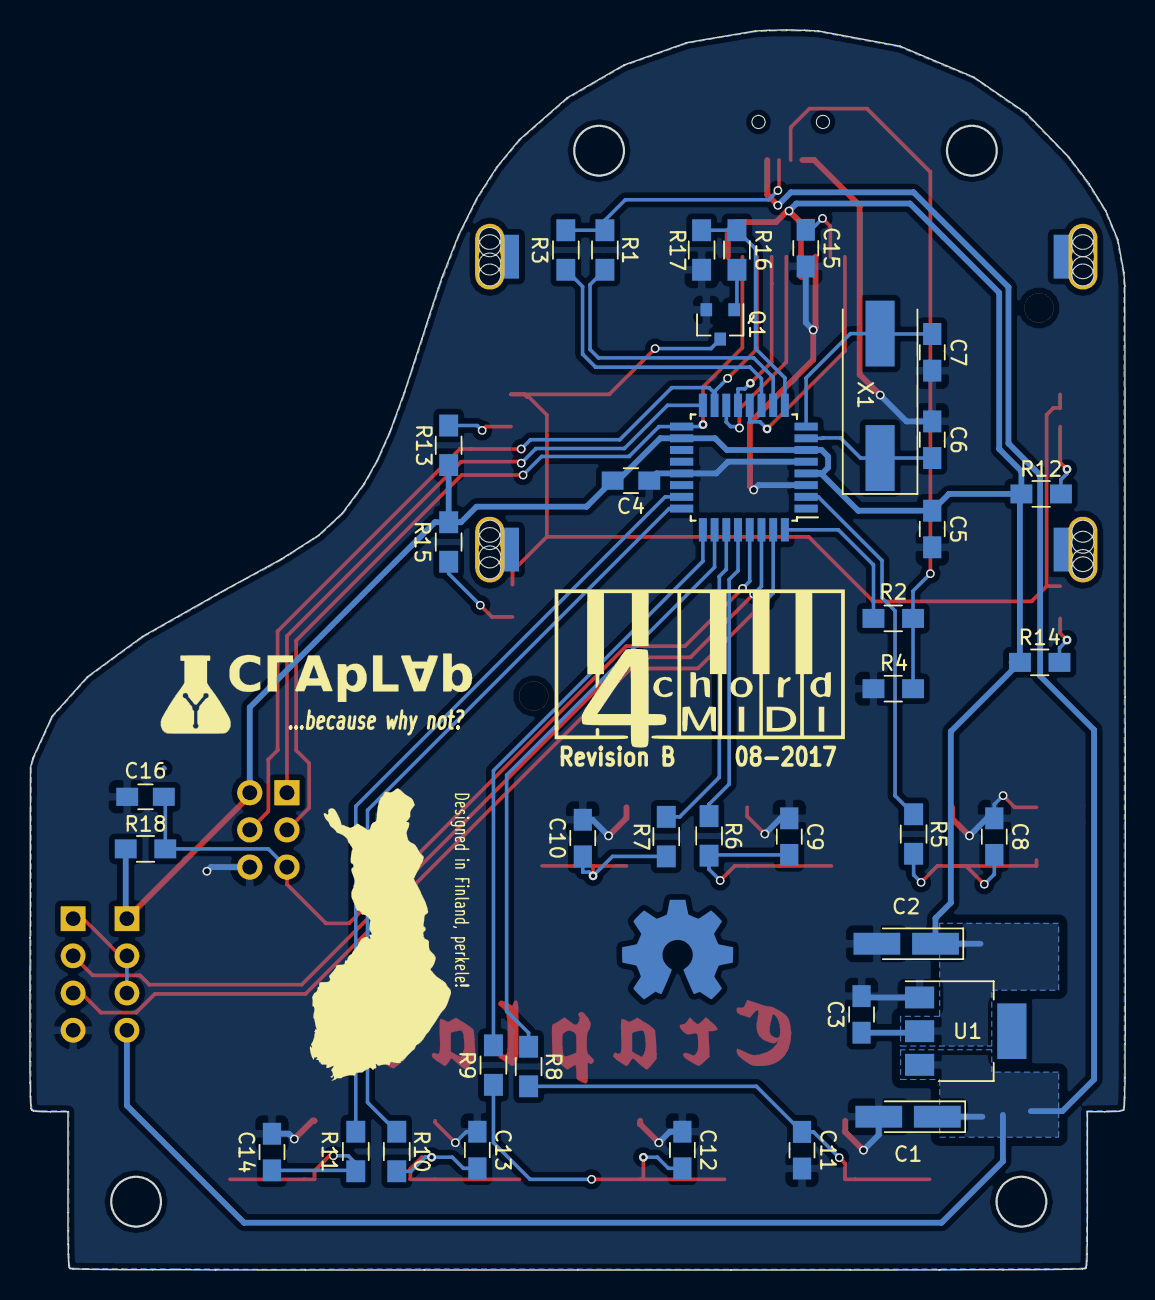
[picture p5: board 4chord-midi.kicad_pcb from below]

Board: 2 copper layers, 74.8 x 84.7 mm, 62 parts (43 on the bottom side), 42 nets.

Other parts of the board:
G1: LOGO; craplab-fraktur-Mask
G2: LOGO; craplab-fraktur-Cu
G3: LOGO; oshw-mask
G4: LOGO; oshw-cooper
G11: qr; projpage-QR-code-inv
G12: 4chordmidi; 4chord-midi
G22: craplab
G31: finland

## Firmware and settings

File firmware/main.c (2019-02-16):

/*
 * 4chord MIDI - main
 *
 * Copyright (C) 2019 Sven Gregori <sven@craplab.fi>
 *
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
 *
 * ATmega328 pin layout (TQFP32)
 *
 *   1  PD3     (unused)
 *   2  PD4     I   Button menu prev
 *   3  GND     -
 *   4  VCC     -
 *   5  GND     -
 *   6  VCC     -
 *   7  PB6     -   XTAL1
 *   8  PB7     -   XTAL2
 *
 *   9  PD5     O   LCD back light
 *  10  PD6     I   USB D-
 *  11  PD7     O   USB Reset
 *  12  PB0     O   LCD /Reset
 *  13  PB1     O   LCD D/C
 *  14  PB2     O   LCD /CS
 *  15  PB3     O   LCD MOSI / SerProg MOSI
 *  16  PB4     I   SerProg MISO
 *
 *  17  PB5     O   LCD SCK / SerProg SCK
 *  18  AVCC    -
 *  19  ADC6    (unused)
 *  20  AREF    -
 *  21  GND     -
 *  22  ADC7    (unused)
 *  23  PC0     I   Button Chord IV
 *  24  PC1     I   Button Chord vi
 *
 *  25  PC2     I   Button Chord V
 *  26  PC3     I   Button Chord I
 *  27  PC4     I   Button Menu Select
 *  28  PC5     I   Button Menu Next
 *  29  PC6     -   /Reset
 *  30  PD0     I   UART RXD
 *  31  PD1     O   UART TXD
 *  32  PD2     I   USB D+
 *
 */
#include <stdint.h>
#include <avr/interrupt.h>
#include <avr/io.h>
#include <util/delay.h>
#include "buttons.h"
#include "cli.h"
#include "eeprom.h"
#include "lcd.h"
#include "menu.h"
#include "xbmlib.h"
#include "intro.h"
#include "gui.h"
#include "playback.h"
#include "spi.h"
#include "timer.h"
#include "uart.h"
#include "usbdrv/usbdrv.h"

/** number of steps to increase the PWM timer value during the intro */
#define INTRO_PWM_STEP_INCREASE 4

/** number of PWM timer increase steps per single intro frame */
#define INTRO_PWM_STEPS_PER_FRAME 5


int
main(void) {
    /* half the frame count of the intro animation, start USB at that point */
    const uint8_t frame_count_usb_threshold = intro_frames_count >> 1;
    /* PWM timer value for fading LCD back light during intro animation */
    uint8_t pwm_value;
    /* intro animation frame count */
    uint8_t frame;
    /* a happy little counter */
    uint8_t i;

    /* set PB0, PB1, PB2, PB3, PB4 as output, rest input */
    DDRB  = (1 << DDB0) | (1 << DDB1) | (1 << DDB2) | (1 << DDB3) | (1 << DDB5);
    /* set PB2 high, all other outputs low, enable pullups for all inputs */
    PORTB = ~((1 << PB0) | (1 << PB1) | (1 << PB3) | (1 << PB5));
    /* set port C all inputs */
    DDRC = 0x00;
    /* enable pullups for all inputs */
    PORTC = 0xff;
    /* set PD1 and PD5 as output, rest input. */
    DDRD  = (1 << DDD1) | (1 << DDD5);
    /* set outputs high, enable pullups for all inputs except V-USB ones */
    PORTD = ~((1 << PD2) | (1 << PD5) | (1 << PD6) | (1 << PD7)) & 0xff;

    uart_init(UART_BRATE_38400_12MHZ);
    uart_clear_screen();

    spi_init();
    lcd_rst_low();

    /* this should give enough delay for the LCD to reset */
    eeprom_init();
    cli_print();

    lcd_rst_high();
    lcd_init();

    /* set up LCD backlight timer and show the first intro animation frame */
    timer0_init_pwm();

    sei();

    /*
     * disconnect USB for a while to get (re-)enumeration ongoing
     * see also http://vusb.wikidot.com/driver-api
     */
    usbDeviceDisconnect();

    /*
     * show the intro animation and fade the back light up
     *  - linear PWM duty cycle increase every 10ms
     *  - show next frame after every 50ms
     * after half the animation frames, connect and initialize USB
     * every animation frame after that, start polling to keep the connection
     */
    for (frame = 0, pwm_value = 0; frame < intro_frames_count; frame++) {
        for (i = 0; i < INTRO_PWM_STEPS_PER_FRAME; i++) {
            timer0_set_pwm(pwm_value);
            pwm_value += INTRO_PWM_STEP_INCREASE;
            _delay_ms(10);
        }

        lcd_write_frame(&intro_frames[frame]);

        if (frame == frame_count_usb_threshold) {
            usbDeviceConnect();
            usbInit();
        } else if (frame > frame_count_usb_threshold) {
            usbPoll();
        }
    }

    /* wait some more to show the logo and slowly get the back light all up */
    while (pwm_value) {
        timer0_set_pwm(pwm_value++);
        usbPoll();
        _delay_ms(50);
    }

    /* map buttons to inputs */
    button_map_port(BUTTON_MENU_PREV,   &PIND, 4);
    button_map_port(BUTTON_MENU_SELECT, &PINC, 5);
    button_map_port(BUTTON_MENU_NEXT,   &PINC, 4);
    button_map_port(BUTTON_CHORD_I,     &PINC, 3);
    button_map_port(BUTTON_CHORD_V,     &PINC, 2);
    button_map_port(BUTTON_CHORD_vi,    &PINC, 1);
    button_map_port(BUTTON_CHORD_IV,    &PINC, 0);

    /* clear the display and show the menu */
    lcd_clear();
    menu_init();

    /* let the magic begin */
    while (1) {
        usbPoll();
        button_input_loop();
        playback_poll();
        menu_poll();
        cli_poll();
    }
}

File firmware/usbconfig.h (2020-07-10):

/* Name: usbconfig.h
 * Project: V-USB, virtual USB port for Atmel's(r) AVR(r) microcontrollers
 * Author: Christian Starkjohann
 * Creation Date: 2005-04-01
 * Tabsize: 4
 * Copyright: (c) 2005 by OBJECTIVE DEVELOPMENT Software GmbH
 * License: GNU GPL v2 (see License.txt), GNU GPL v3 or proprietary (CommercialLicense.txt)
 */

/*
 * Based on vusb-20121206/usbdrv/usbconfig-prototype.h
 * Adjusted for the 4chord MIDI project
 */

#ifndef __usbconfig_h_included__
#define __usbconfig_h_included__

/* ---------------------------- Hardware Config ---------------------------- */

#define USB_CFG_IOPORTNAME      D
/* This is the port where the USB bus is connected. When you configure it to
 * "B", the registers PORTB, PINB and DDRB will be used.
 */
#define USB_CFG_DMINUS_BIT      6
/* This is the bit number in USB_CFG_IOPORT where the USB D- line is connected.
 * This may be any bit in the port.
 */
#define USB_CFG_DPLUS_BIT       2
/* This is the bit number in USB_CFG_IOPORT where the USB D+ line is connected.
 * This may be any bit in the port. Please note that D+ must also be connected
 * to interrupt pin INT0! [You can also use other interrupts, see section
 * "Optional MCU Description" below, or you can connect D- to the interrupt, as
 * it is required if you use the USB_COUNT_SOF feature. If you use D- for the
 * interrupt, the USB interrupt will also be triggered at Start-Of-Frame
 * markers every millisecond.]
 */
#define USB_CFG_CLOCK_KHZ       (F_CPU/1000)
/* Clock rate of the AVR in kHz. Legal values are 12000, 12800, 15000, 16000,
 * 16500, 18000 and 20000. The 12.8 MHz and 16.5 MHz versions of the code
 * require no crystal, they tolerate +/- 1% deviation from the nominal
 * frequency. All other rates require a precision of 2000 ppm and thus a
 * crystal!
 * Since F_CPU should be defined to your actual clock rate anyway, you should
 * not need to modify this setting.
 */
#define USB_CFG_CHECK_CRC       0
/* Define this to 1 if you want that the driver checks integrity of incoming
 * data packets (CRC checks). CRC checks cost quite a bit of code size and are
 * currently only available for 18 MHz crystal clock. You must choose
 * USB_CFG_CLOCK_KHZ = 18000 if you enable this option.
 */

/* ----------------------- Optional Hardware Config ------------------------ */

#define USB_CFG_PULLUP_IOPORTNAME   D
/* If you connect the 1.5k pullup resistor from D- to a port pin instead of
 * V+, you can connect and disconnect the device from firmware by calling
 * the macros usbDeviceConnect() and usbDeviceDisconnect() (see usbdrv.h).
 * This constant defines the port on which the pullup resistor is connected.
 */
#define USB_CFG_PULLUP_BIT          7
/* This constant defines the bit number in USB_CFG_PULLUP_IOPORT (defined
 * above) where the 1.5k pullup resistor is connected. See description
 * above for details.
 */

/* --------------------------- Functional Range ---------------------------- */
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

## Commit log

2015-11-15 Initial commit, basic button handling, LCD handling and GUI
2015-11-19 issue-#3: integration of V-USB (and adding sources), setting up MIDI descriptors
    [main.c, usbconfig.h]
2015-11-21 issue-#3: adjust fuses and firmware to 16MHz external clock
    [main.c]
2015-11-21 Add fuse dump tool to display AVR ATmega328p fuse byte settings
2015-11-22 issue-#3: re-arrange startup code to make USB work
    [main.c]
2015-11-22 issue-#3: Added single-note MIDI playback on chord button press
2015-12-03 Added KiCad project for ATmega328-TQFP32
2015-12-03 issue-#1: Added schematic revision A for ATmega328-TQFP32
    [4chord-midi.sch]
2015-12-03 Added KiCad backup and cache files
2015-12-03 issue-#1: fixed broken connection R4-GND
    [4chord-midi.sch]
2015-12-03 issue-#1: Added test points and zero-Ohm links
    [4chord-midi.sch]
2015-12-04 issue-#1: Added ground test points / pins
    [4chord-midi.sch]
2015-12-06 issue-#2: Added component footprints
    [4chord-midi.sch]
2015-12-06 issue-#2: Removed some grounding pins and changed footprints of remaining ones
    [4chord-midi.sch]
2015-12-14 issue-#2: Added KiCad PCB layout
    [4chord-midi.kicad_pcb]
2015-12-14 issue-#2: Added Gerber files (KiCad naming scheme)
    [4chord-midi-B.Cu.gbr, 4chord-midi-B.Mask.gbr, 4chord-midi-B.SilkS.gbr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]
2015-12-14 Added KiCad PCB backup file
2015-12-14 Added comments on PCB artwork
2015-12-14 issue-#3: Added OSH Park compliant Gerber files as ZIP archive and script to create the ZIP archive from KiCad 4 naming scheme
2015-12-18 issue-#4: Moved menu handling from gui.c to new menu.c
    [main.c]
2015-12-19 Added CERN OHL v.1.2 licensing documentation
    [4chord-midi.kicad_pcb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]
2015-12-19 issue-#5: Added progressive playback handling for arpeggio and mixed chord/arpeggio modes
    [main.c]
2015-12-20 issue-#5: Changed timer value calculation to avoid floating point operation
2015-12-20 issue-#5: Added UART command line interface handling for button emulation
    [cli.c, main.c]
2015-12-20 issue-#5: Removed unused case code
    [cli.c]
2017-06-17 issue-#12: Initial version for Revision B hardware
    Changed crystal value from 16MHz to 12MHz to match speed spec for
    ATmega running at 3.3V. Changed LCD from Olimex Nokia 3310 with hard
    to find connector to Nokia 5110 breakout board style so it can be
    clipped directly into the PCB. Added LED based back light as well.
    Adjusted some pin assignments for ongoing PCB design
    Added BOM along the way.
    [4chord-midi-B.Cu.gbr, 4chord-midi-B.Mask.gbr, 4chord-midi-B.SilkS.gbr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]
2017-07-02 issue-#12: Completing Revision B schematic
    Further pin adjustments to get better PCB routing done. Changed
    programmer header from 10pin to 6pin for same reason.
    [4chord-midi.sch]
2017-07-02 issue-#13: Initial Revision B PCB design
    Piano shaped PCB with debug interfaces: zero ohm links to all major
    power supplies, GND and UART voltage supply; GND test point; allows
    external (USB) UART connection (NOTE: do not equip R20 if USB UART
    controller is used)
    [4chord-midi.kicad_pcb]
2017-07-23 issue-#14: Adjust firmware to Revision B hardware changes
    Adjusted pin assignments according to Revision B hardware, changed clock
    frequency define from 16MHz to 12MHz (and re-arranged and neated up the
    Makefile along the way), enabled LCD backlight and changed LCD's bias
    system value for Nokia 5110 display.
    All okay in theory, waiting for PCB to build hardware and fully verify.
    [cli.c, main.c, usbconfig.h]
2017-08-01 issue-#14: Adjust UART baud rate values for 12MHz
    Removed 8MHz and 16MHz based baud rate register values and added 12MHz
    values for baud rates 9600, 19200, 38400 and 57600. Kept 38400 as
    default value for now.
    Note, tried 115200, but error was too large.
    [main.c, uart.h]
2017-08-09 issue-#13: Revised Revision B hardware
    Reworked schematic to separate to logical blocks, added reset circuit,
    fixed Q1 pin assignment and changed it from BJT to MOSFET component.
    Also added power supply choices for UART (5V, 3.3V and none) and a
    fourth rubber foot for better balance.
    Obviously same changes in the PCB design, also moved button silk screen
    bit more down for better readability. Fixed one sharp corner in the
    board border. Improved routing somewhat.
    [4chord-midi-B.Cu.gbl, 4chord-midi-B.Mask.gbs, 4chord-midi-B.Paste.gbp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]
2017-08-09 issue-#14: Changed USB VID/PID to 4chord MIDI's own
    Cheers to pid.codes for making this possible.
    [usbconfig.h]
2017-08-19 issue-#15 Finalized Revision B hardware
    Final little touches here and there on the PCB design, mainly silk
    screen adjustments and moved the upper rubber feet.
    Alos, fucked up 00f85adde54214f45f219a16524527a8af92649b which should
    have been linked to issue-#15 as well. Oh well..
    [4chord-midi-B.Cu.gbl, 4chord-midi-B.Mask.gbs, 4chord-midi-B.Paste.gbp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]
2017-08-19 issue-#14 Increase firmware version for Rev.B hardware
    Also updating Rev.B date to latest design
    [cli.c, config.h]
2017-08-26 Added udev rule example
    Simple udev rule example to automatically start fluidsynth and set up
    the MIDI connection to it whenever a 4chord MIDI device is plugged in,
    and clean it up again when the device is unplugged.
2017-09-12 Add schematic cache lib to repository
    Otherwise it's just fucked up anyway since KiCad generates default
    netlist now to reference the cache lib instead of the builtin
    components. Probably best this way with changes happening now and then
    in the builtin ones. Which I fixed here too, since someone had the grand
    idea to change the USB-B component's pin arrangement to 1-3-2-4-5 and
    swap D+ and D- order.
    [4chord-midi.kicad_pcb, 4chord-midi.sch]
2017-10-19 issue-#17: Initial bootloader implementation
    Added device side bootloader implementation and host side Python script
    as flashing tool. Heavy restructuring of the Makefiles along the way to
    keep most of the overlapping parts in a common place.
    [lcd.c, main.c, spi.c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]
2017-10-20 issue-#17: Adjusted USB config for PID and name
    [usbconfig.h]
2017-10-20 issue-#17: Improved bootloader flash tool
    Cleaned up the proof of concept Python script to flash a new firmware
    through the bootloader. Simple output as default, detailed per-page
    output with additional verbose mode
    [bootflash.py]
2017-10-26 issue-#23: Discarded LCD content buffering
    Instead of keeping a buffered copy of the whole LCD memory around, and
    using up a big chunk of RAM for that, LCD data is written directly as-is
    via SPI now.
    Added support for frame diff based animations from xbm2nokia project,
    and included a funky startup animation. There's some room for
    improvement, and general graphics are still on TODO to include here
    (and preferably combine with the animation).
    Added LCD back light support via timer0 PWM along the way.
    Some minor cleanup and adjustments here and there.
    [cli.c, config.h, lcd.c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]
2017-10-27 issue-#21: Added long press for menu buttons
    Got tired of single button press, especially when changing the tempo, so
    now there is long button press support for the menu buttons.
    For the "<" and ">" menu button, it keeps executing the prev and next
    functions. First with a 500ms delay for the first three iterations, then
    it speeds up to 100ms.
    For the "Select" menu button, long press will wait 1.5s and for now only
    set the LCD to inverse video mode. Later on this will open a separate
    configuration menu.
    Long press shares the same timer as the chord playback uses. There's
    still timer2 available, but that's an 8bit timer, and this kinda needs
    16bit timer values - or then an additional counter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
    [cli.c, main.c]
2017-10-28 issue-#19: Added chord list to LCD w/ highlight
    Each key's four chord's are now displayed on the LCD for easier
    visualization of what's actually available in each key. This should make
    it easier to play songs by chord - and also to find out whether a song
    is a 4chord song or not.
    It felt like a good idea to create a "font" for this instead of using
    individual graphics. Using quotes cause it doesn't really make any real
    difference - both is just data representing pixels on the LCD.
    Added also highlighting the currently played chord. So whenever one of
    the four chord buttons is pressed, the corresponding one is lighting up
    on the LCD - and goes back to normal when the button is released.
    [cli.c, lcd.c]
2017-10-28 issue-#20: Added metre playback and display support
    General support for metre concept added, and included new 3/4 and 6/8
    playback next to the regular 4/4 one. Well, at this current point, since
    all playback is based on 1/8 notes, the there is no difference between
    3/4 and 6/8 apart from LCD content.
    Added a font for this as well, could use some improvements still if
    something like 12/8 metre should be supported (there's only one digit
    supported for now, so.. yeah.)
    Also added a little metronome to arpeggio playback (there's no point in
    showing a metronome without beat as in the chord playback mode), no idea
    if anyone has actual any use to it, but there was this little piece of
    LCD space l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
    [lcd.c]
2018-05-07 issue-#25: Basic EEPROM support added to build system
    Added Makefile rules to create and flash EEPROM data from the ELF file,
    and changed fuse bits to preserve EEPROM during chip erase.
2018-05-07 issue-#25: Initial EEPROM data handling added
    Dummy EEPROM data defined and files are added to Makefile
    [eeprom.c]
2018-05-07 issue-#25: Playback init values are read from EEPROM
    Init values for playback chord/mode/metre/tempo are now stored on the
    EEPROM and menu initialization is based on those values.
    Long press on the Select key will store the current playback values as
    new init values to the EEPROM (still to be replaced by a general menu
    later on)
    [eeprom.c]
2018-12-22 issue-#25: EEPROM data is validated and sanitized
    Ensure the data stored in EEPROM is somewhat sanitized and within the
    expected range. If not, the data is overwritten with default fallback
    values.
    Writing EEPROM data will warn about possible consequences and needs
    response before proceeding. Optionally the current EEPROM content is
    read back and stored to a file.
    [cli.c, eeprom.c, main.c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]
2018-12-23 issue-#28: Replaced graphics generation script with xbmtool
    XBM graphics are now converted using xbmtool.sh instead of the old
    create_graphics.sh script.
    Graphics generation support now both full frame / as-is data and diff
    frame based animations that modify only the values that changed to the
    previous animation frame.
    Also, input graphics don't need to be rotated and flipped anymore, but
    the XBM files can be taken as they are, the conversion itself will
    handle all data arrangements itself.
2018-12-23 issue-#28: Firmware uses new graphics
    Added support for xbmtool generated graphics data, adjusted everything
    accordingly and added all new generated graphics sources.
    [lcd.c, main.c]
2019-02-16 Some random, minor cleanup and fixes
    - xbmtool doesn't abort `make` anymore if files aren't overwritten
    - udev install script didn't fully obey overwrite-existing-file choice,
    now it does and also outputs a tad more information
    - added some more information and debug output to fluidsynth script
    - added also some information about known issue with that script
    - cleaned up intro animation / light fading / USB init handling
    - removed unused V-USB callback functions
    - bootloader debug output showed a wrong address
    - renamed chord button constants from 1, 2, 3, 4 to I, V, vi, IV
    - added `make size` option to print firmware size
    [lcd.c, main.c, usbconfig.h]
2019-11-19 Bootflash script uses finally Python 3
    Dumped a bunch of parantheses around the prints.
    Also changed everything about the output in general, now with ASCII art!
2019-11-20 xbmtool integration for bootloader graphics
    Using same xbmtool generation as for firmware also for the bootloader,
    changed the bootloader screen, and gently optimized some SPI parts.
2020-06-13 Added Makefile rule to check programmer state
    To quickly check that the programmer is set up correctly and the ATmega
    is recognized, new Makefile rule is added.
    Programmer settings for avrdude was extracted into an own Makefile
    variable for easier adjustments to other programmers.
    Also made a global accessible fuse burning rule
2020-06-13 Added file permission udev rule for flashing via bootloader
    Regular user might not have write permissions to flash a new firmware to
    the device via bootloader. Udev rule will set up write permissions, and
    the install script in sys/udev/ will copy it to /etc
2020-06-13 Added bootloader version string verification to bootflash
    Just in case, additional check is added to make sure the connected
    device identifies itself as valid 4chord MIDI bootloader device.
    Also, reading ASCII tables is hard, so the HELLO command values were
    messed up.
2020-06-13 issue-#24: Updated and extended project's main README
    Add sections about building, flashing, and using the device
2020-07-10 Increased SPI clock speed
    SPI was set up to use F_CPU/16 clock speed, while F_CPU/4 will do just
    fine as it results in 12.0MHz/4 = 3.0MHz which falls well into the LCD
    controller's <=4.0MHz limitation.
    As a result, there is a tiny hint less ghosting / delay in the display
    updating now.
2020-07-10 Fixed file headers for consistency
    It's now everywhere "4chord MIDI", in some places the "MIDI" wasn't
    capitalized. Seriously important work done here, I tell you.
    [lcd.c, uart.c, uart.h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]
2020-07-10 Added short delay in bootloader UART output
    If the bootloader doesn't get activated but jumps straight to the
    application code, the UART might not finish its output in time and
    causes some garbage output. Things gotta look pretty, eh?
    [main.c]
2020-07-10 Remove assembly listing files during make clean
    Used to be removed during `make distclean`, but kinda makes no sense as
    the .lst listing files belong to the .o files that are cleaned during
    `make clean` anyway.
2020-07-23 Fixed old links to USB specifications
    Links to usb.org specifications have changed and resulted in 404, also
    message summary link to midi.org gets redirected to a new location, but
    who knows for how long, so updated the location just in case.
2020-07-23 Added doc/ directory with local copies of relevant docs and specs
    Since the links to specifications were broken, I figured it's maybe best
    to just add a local copy just in case. While those links probably won't
    ever fully disappear, it's still annoying to end up with a 404 and
    having to search for the new location. So now they're also in the repo.
2020-08-21 Lowered PWM timer prescaler / increased PWM timer speed
    At F_CPU/256 prescaler, there's some subtle flickering noticable in some
    situations, especially when the entire display is filled. Might not be
    all too relevant in real world scenarios, but at F_CPU/64 prescaler, the
    flickering is gone, so, tadaa.
2020-08-21 Moved some LCD init values to EEPROM
    Looks like different LCDs might require different init values to look
    nice and clear. Specifically the V_op value might be affected here, but
    possibly also temperature coefficient or bias system value ..maybe, it
    remains to be seen.
    But in any case, those three values are now stored in the EEPROM and
    read back during lcd_init().
2025-01-04 Tweak kitspace.org description
    Set additional information and add a CSV BOM
    [4chord-midi.bom.csv]
2025-01-04 Minor fixes
    make size target didn't have the .elf file as dependencies, causing
    issues when running multiple jobs in parallel. Adding dependency should
    now also build nicely in parallel.
    Adjustments to deprecated, ancient ways of Python, and some output tweak
    [bootflash.py]

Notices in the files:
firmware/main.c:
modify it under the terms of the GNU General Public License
